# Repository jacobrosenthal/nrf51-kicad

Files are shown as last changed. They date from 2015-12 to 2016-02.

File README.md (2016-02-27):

Nordic provides reference designs for Altium only:
https://www.nordicsemi.com/eng/nordic/download_resource/20348/9/5180704

This is the qfac-dcdc from 2.4

Ideally you could use altium's free www.circuitmaker.com to view the paid Circuit Designer files, but thats not the case unless they have already previously been exported as an autocad file:
https://www.youtube.com/watch?v=YAWBsShCId4

As thats not the case for these Nordic files I decided to play.

In the end I finally found a 'free' viewer (for 6 months) from Altium that is really all you need to get a look at the design decisions.
http://www.altium.com/altium-designer-viewer 

However I wanted to play with kicad and https://github.com/thesourcerer8/altium2kicad to see how close it gets

Fixed issues:
* Schematic wouldnt come over for some reason, I had to build that by hand.
* The Polygons didn't come in quite right, I made them Thermal Releif's and Polygons and that seemed to help.
* I dont think you can bring in bare pads, so the antenna pad was lost on import and its signal trace was downsized. 
* Keepout Polys were lost and recreated by hand
* Stiching Vias are.. problematic, in kicad so those needed to be handled by hand https://forum.kicad.info/t/protip-nicer-via-stitching/1103/32
* via drill conversion was wierd, though Im not familar enough with kicad right now to know if it mattered, I hand edited all those a bunch
* File-Archive Footprints->Create library Exported the footprints out of the design into a proper library, and moved the .3dshapes locally as well

Known issues:
* Keepouts are really picky in kicad and Im so far too lazy to stich around all the pads, so traces in that region are showing as airwires even though theyre connected
* Altium has the no poly islands smaller than xsq but kicad doesnt appear to which means a few little islands exist on our gerbers that dont on theirs.

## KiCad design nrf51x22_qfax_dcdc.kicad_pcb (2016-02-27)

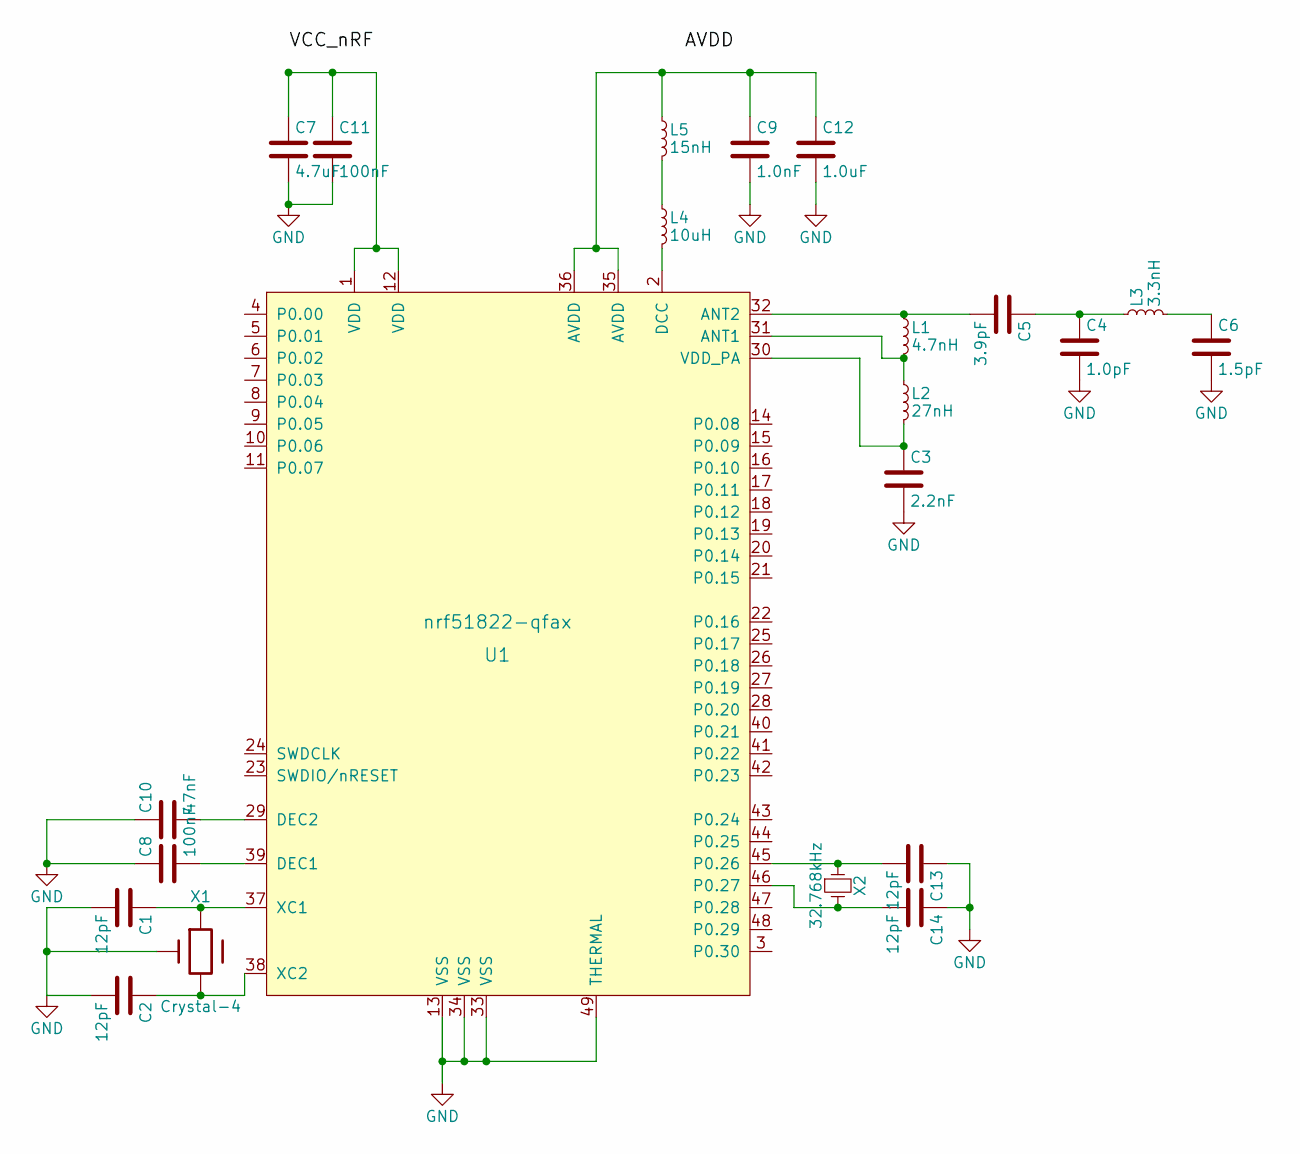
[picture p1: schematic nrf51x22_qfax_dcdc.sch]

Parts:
C1, C2, C13, C14: 12pF; CAPC1005X04L
C3: 2.2nF; CAPC1005X04L
C4: 1.0pF; CAPC1005X04L
C5: 3.9pF; CAPC1005X04L
C6: 1.5pF; CAPC1005X04L
C7: 4.7uF; CAPC1608X06L
C8, C11: 100nF; CAPC1005X04L
C9: 1.0nF; CAPC1005X04L
C10: 47nF; CAPC1005X04L
C12: 1.0uF; CAPC1608X06L
L1: 4.7nH; INDC1005X04L
L2: 27nH; INDC1005X04L
L3: 3.3nH; INDC1005X04L
L4: 10uH; INDC1608X06L
L5: 15nH; INDC1005X04L
U1: nrf51822-qfax; nrf51-qfax-1ep-vias
X1: Crystal-4; BT-XTAL_2520
X2: 32.768kHz; XTAL_3215

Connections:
GND: C1.2, C2.2, C3.2, C4.2, C6.2, C7.2, C8.1, C9.2, C10.1, C11.2, C12.2, C13.1, C14.1, U1.13 (VSS), U1.33 (VSS), U1.34 (VSS), U1.49 (THERMAL), X1.2 (4), X1.4
unnamed: C1.1, U1.37 (XC1), X1.3
unnamed: C2.1, U1.38 (XC2), X1.1
unnamed: C3.1, L2.2, U1.30 (VDD_PA)
unnamed: C4.1, C5.1, L3.1
unnamed: C5.2, L1.1, U1.32 (ANT2)
unnamed: C6.1, L3.2
unnamed: C8.2, U1.39 (DEC1)
unnamed: C10.2, U1.29 (DEC2)
unnamed: C7.1, C11.1, U1.1 (VDD), U1.12 (VDD)
unnamed: C9.1, C12.1, L5.1, U1.35 (AVDD), U1.36 (AVDD)
unnamed: C13.2, U1.45 (P0.26), X2.1
unnamed: C14.2, U1.46 (P0.27), X2.2
unnamed: L1.2, L2.1, U1.31 (ANT1)
unnamed: L4.1, L5.2
unnamed: L4.2, U1.2 (DCC)

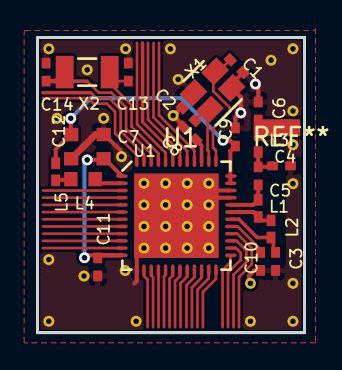
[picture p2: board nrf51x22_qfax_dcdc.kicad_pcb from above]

Board: 2 copper layers, 14.8 x 16.4 mm, 22 parts (0 on the bottom side), 16 nets.

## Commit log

2015-12-12 fresh export of dcdc
    [sticker.kicad_pcb]
2015-12-15 add schematic, symbols, export footprints, clean up
    [sticker.kicad_pcb, sticker.sch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]
2015-12-15 name change
    [nrf51x22_qfax_dcdc.kicad_pcb, nrf51x22_qfax_dcdc.sch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]
2015-12-15 missed replacing a via
    [nrf51x22_qfax_dcdc.kicad_pcb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]
2015-12-24 refer to local copies of footprint libraries
2015-12-25 library update
    [nrf51x22_qfax_dcdc.kicad_pcb, nrf51x22_qfax_dcdc.sch]
2015-12-25 add vias to footprint and swap in
    [nrf51x22_qfax_dcdc.kicad_pcb, nrf51x22_qfax_dcdc.sch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]
2016-02-27 fix crystal component so hooks grounds to GND, gerbers
    [nrf51x22_qfax_dcdc.kicad_pcb, nrf51x22_qfax_dcdc.sch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]
2016-02-27 fix missing low freq crystal on schematic
    [nrf51x22_qfax_dcdc.kicad_pcb, nrf51x22_qfax_dcdc.sch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]
2016-02-27 fill in component fields for bom
    [nrf51x22_qfax_dcdc.sch]
